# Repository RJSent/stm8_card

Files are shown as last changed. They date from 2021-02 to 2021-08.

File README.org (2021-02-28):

#+TITLE: stm8_card
#+AUTHOR: Richard Sent

* Overview

This is a work-in-progress project for an STM8 microcontroller powered
business card. I am using an STM8 alongside a OLED with a SSD1306
controller.

I've finished implementing most basic functionality (UART, I2C, etc)
and have begun working on the business card proper. There's still a
fair amount of work left to do. In particular, I need to implement
timers (instead of ~delay~), user input (debounced buttons), and a
low-power mode using interrupts. Of course, there's also more to be
done regarding the display itself!

I working to keep most of my code generic enough that I can reuse it
in future projects without needing to rework everything. It will act
as a miniature library of sorts for me to use. When that happens I
might move that to a different git project, and leave business card
specific code here.

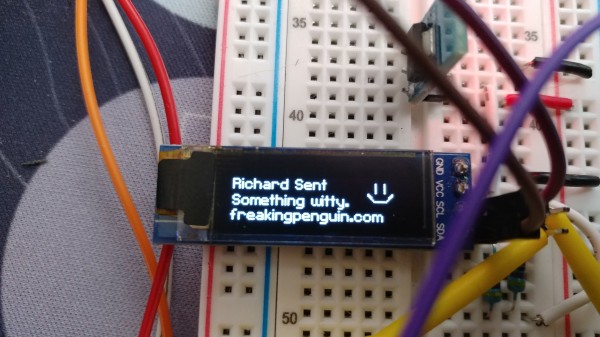
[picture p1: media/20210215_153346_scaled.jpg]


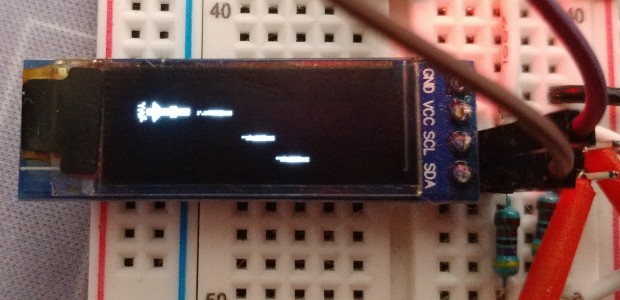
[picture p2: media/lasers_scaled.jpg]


[[file:media/working_lasers.mp4][Here's a demonstration of a work in progress space invaders game!]] We
can see that the player ship and lasers are functional and fully
animated. If you want to see the work that led up to this so far,
check out the media folder!

* License

This project is available under the terms of the [[https://opensource.org/licenses/MIT][MIT License]].

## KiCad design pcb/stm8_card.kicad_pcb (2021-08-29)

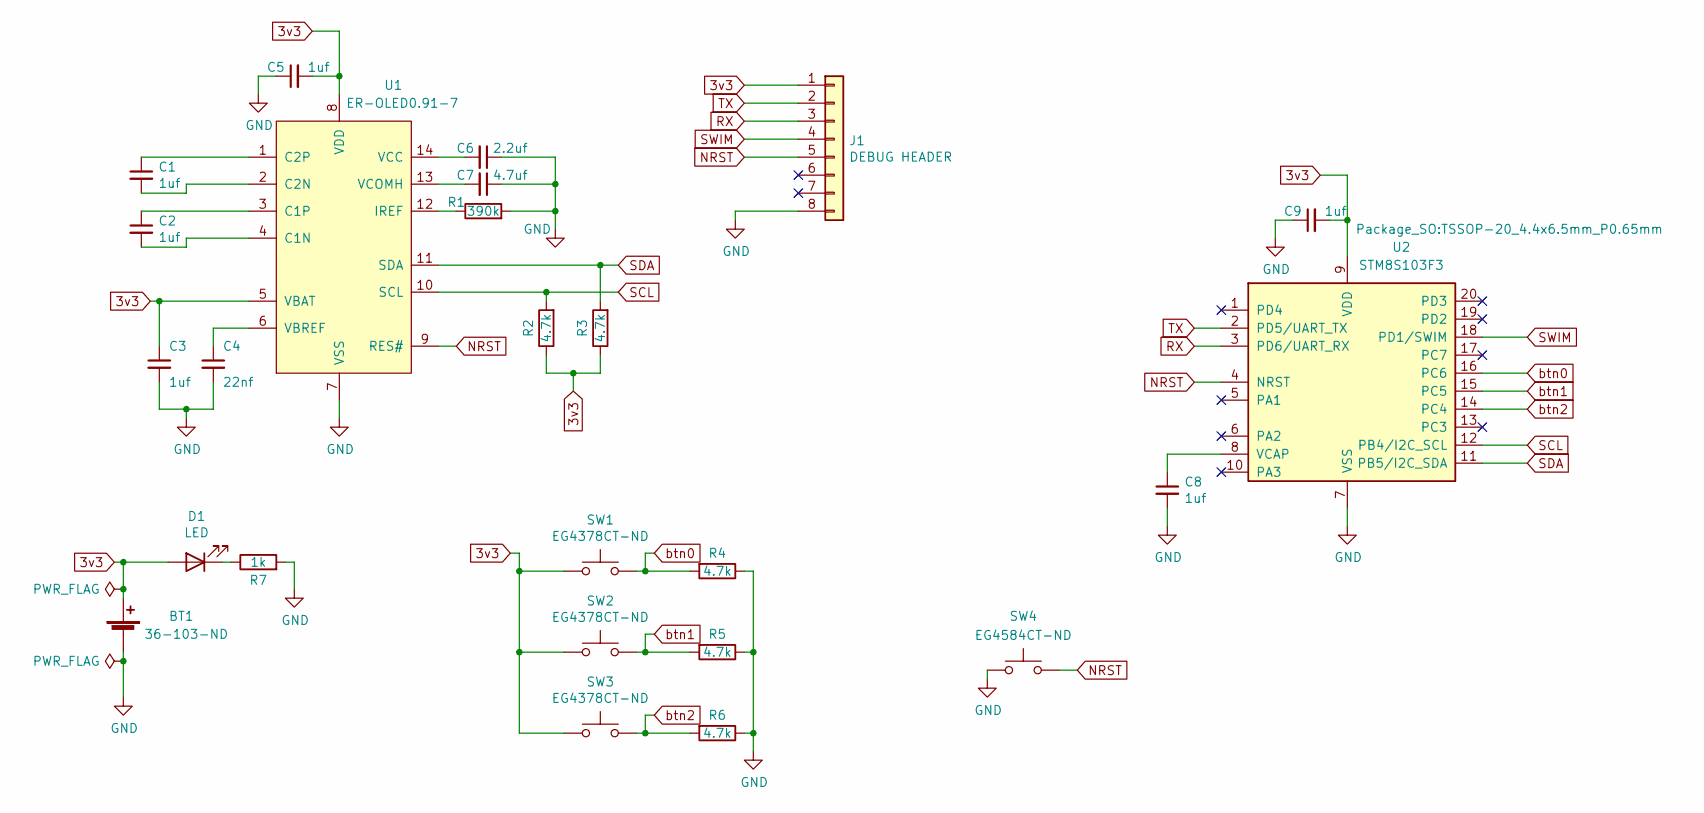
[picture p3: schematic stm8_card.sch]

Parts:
BT1: 103; BatteryHolder_Keystone_103_1x20mm_Corrected; digikey 36-103-ND
C1, C2, C3, C5, C8, C9: 1uf; C_0805_2012Metric_Pad1.18x1.45mm_HandSolder
C4: 22nf; C_0805_2012Metric_Pad1.18x1.45mm_HandSolder
C6: 2.2uf; C_0805_2012Metric_Pad1.18x1.45mm_HandSolder
C7: 4.7uf; C_0805_2012Metric_Pad1.18x1.45mm_HandSolder
D1: LED; LED_0805_2012Metric_Pad1.15x1.40mm_HandSolder; digikey 404-1316-1-ND
J1: DEBUG HEADER; 2mm_2x4_ICSP
R1: 390k; R_0805_2012Metric_Pad1.20x1.40mm_HandSolder
R2, R3, R4, R5, R6: 4.7k; R_0805_2012Metric_Pad1.20x1.40mm_HandSolder
R7: 1k; R_0805_2012Metric_Pad1.20x1.40mm_HandSolder
SW1, SW2, SW3: TL59AF100Q; digikey EG4378CT-ND
SW4: TL3302AF260QG; digikey EG4584CT-ND
U1: ER-OLED0.91-7
U2: STM8S103F3; TSSOP-20_4.4x6.5mm_P0.65mm

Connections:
3v3: BT1.1 (+), C3.1, C5.2, C9.2, D1.2 (A), J1.1, R2.1, R3.1, SW1.1, SW2.1, SW3.1, U1.5 (VBAT), U1.8 (VDD), U2.9 (VDD)
GND: BT1.2 (-), C3.2, C4.2, C5.1, C6.1, C7.1, C8.2, C9.1, J1.8, R1.2, R4.1, R5.1, R6.1, R7.2, SW4.1, U1.7 (VSS), U2.7 (VSS)
NRST: J1.5, SW4.2, U1.9 (RES#), U2.4 (NRST)
unnamed: C1.1, U1.1 (C2P)
unnamed: C1.2, U1.2 (C2N)
unnamed: C2.1, U1.3 (C1P)
unnamed: C2.2, U1.4 (C1N)
unnamed: C4.1, U1.6 (VBREF)
unnamed: C6.2, U1.14 (VCC)
unnamed: C7.2, U1.13 (VCOMH)
unnamed: C8.1, U2.8 (VCAP)
unnamed: D1.1 (K), R7.1
unnamed: R1.1, U1.12 (IREF)
RX: J1.3, U2.3 (PD6/UART_RX)
SCL: R2.2, U1.10 (SCL), U2.12 (PB4/I2C_SCL)
SDA: R3.2, U1.11 (SDA), U2.11 (PB5/I2C_SDA)
SWIM: J1.4, U2.18 (PD1/SWIM)
TX: J1.2, U2.2 (PD5/UART_TX)
btn0: R4.2, SW1.2, U2.16 (PC6)
btn1: R5.2, SW2.2, U2.15 (PC5)
btn2: R6.2, SW3.2, U2.14 (PC4)

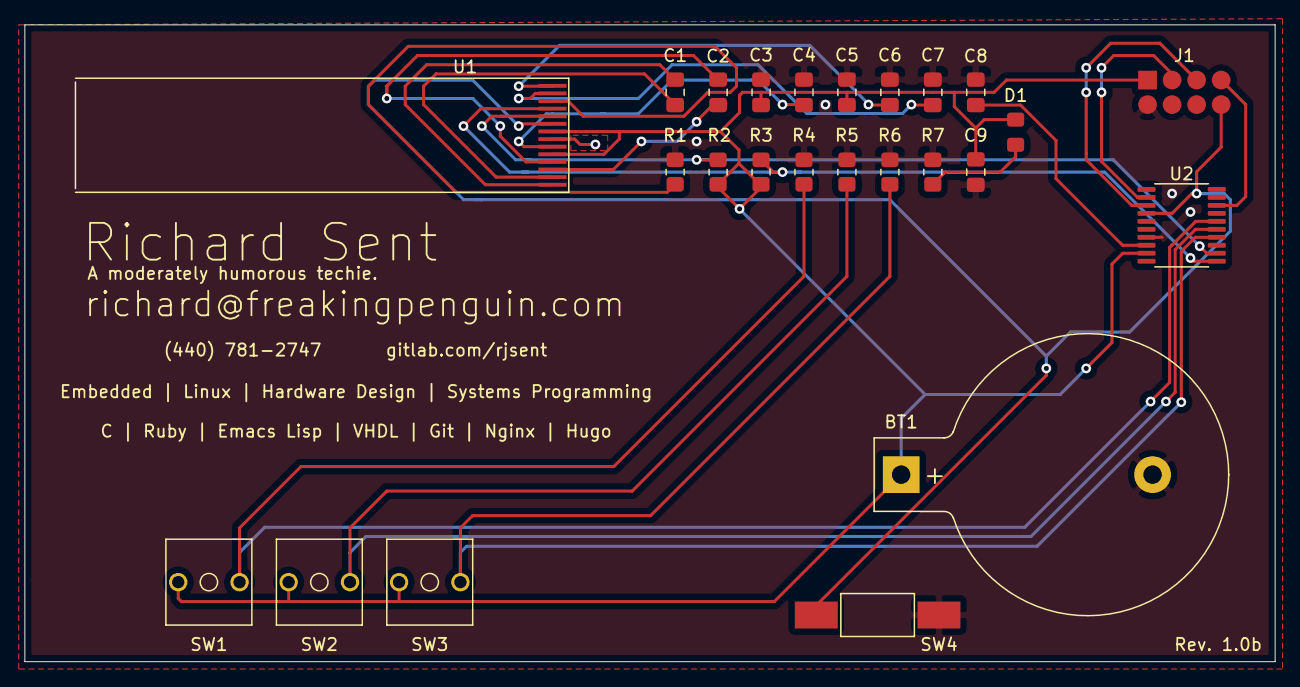
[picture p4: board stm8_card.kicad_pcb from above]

Board: 2 copper layers, 101.9 x 51.9 mm, 25 parts (0 on the bottom side), 21 nets.

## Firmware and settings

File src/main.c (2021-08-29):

#include <stdlib.h>

#include "baseline.h"
#include "i2c.h"
#include "uart.h"
#include "ssd1306.h"
#include "image.h"
#include "space_invader.h"
#include "gpio.h"

gpio_pin_t btn0 = { .port = 'C', .num = 6 };
gpio_pin_t btn1 = { .port = 'C', .num = 5 };
gpio_pin_t btn2 = { .port = 'C', .num = 4 };
gpio_pin_t led0 = { .port = 'A', .num = 1 };
gpio_pin_t led1 = { .port = 'A', .num = 2 };

static void initialize_gpio() {
  gpio_mode(&btn0, GPIO_INPUT_FLOAT);
  gpio_mode(&btn1, GPIO_INPUT_FLOAT);
  gpio_mode(&btn2, GPIO_INPUT_FLOAT);
  gpio_mode(&led0, GPIO_OUTPUT_PUSH_PULL);
  gpio_mode(&led1, GPIO_OUTPUT_PUSH_PULL);
}

/* TODO: move to power saving.c/h and take struct for what to gate */
static void periph_gating() {
  *CLK_PCKENR1 &= 0x1;           /* only i2c enabled */
  // *CLK_PCKENR1 |= 1 << 3;        /* enable uart1 */
  *CLK_PCKENR2 &= !(0x8C);      /* 0 to everything not reserved, rm0016 pg 96 */
}

static void power_saving() {
  clk_hsi_prescaler(1);
  clk_cpu_prescaler(128);        /* 125 kHz cpu */
  periph_gating();
  
}

static void initialize() {
  const int baud_rate = 9600;
  const long fmaster = 16000000;

  power_saving();

  uart_init(baud_rate, fmaster);
  i2c_init(2);
  initialize_gpio();
  ssd1306_init(SSD1306_I2C);
  invader_game_init(SSD1306_WIDTH, SSD1306_HEIGHT);
}

int main() {
  initialize();
  uart_printf("%s\n\r", __DATE__);
  char cycle_num = 0;
  const char max_cycles = 10;

  while (1) {
    /* uart_printf("-----CYCLE %d-----\n\r", cycle_num); */
      struct InvaderCommands invader_commands;
      if (gpio_read(&btn0)) {
	gpio_write(&led0, true);
	gpio_write(&led1, false);
	invader_commands.movement = DOWN;
      } else if (gpio_read(&btn1)) {
	gpio_write(&led0, false);
	gpio_write(&led1, true);
	invader_commands.movement = UP;
      } else {
	gpio_write(&led0, false);
	gpio_write(&led1, false);
	invader_commands.movement = NOP;
      }
      /* debounded input here. Maybe just have as timer though for
	 extra button to exit */
      if (random_upto(32) > 30) {
	invader_commands.shoot = TRUE;
      }
      struct DrawableImage *spaceship = debug_drawableimage_spaceship();
      invader_game_tick(&invader_commands);
      draw_image(spaceship, LEFT);
      struct DrawableImage *lasers[3];
      struct DrawableImage *invader_lasers[3];
      struct DrawableImage *invaders[3];
      for (int i = 0; i < 3; i++) {
	lasers[i] = debug_drawableimage_playerlaser(i);
	invader_lasers[i] = debug_drawableimage_invaderlaser(i);
	invaders[i] = debug_drawableimage_invader(i);
	draw_image(lasers[i], LEFT);
	draw_image(invader_lasers[i], LEFT);
	draw_image(invaders[i], LEFT);
      }
      draw_half(LEFT);
      clear_buffer();
      for (int i = 0; i < 3; i++) {
	draw_image(lasers[i], RIGHT);
	draw_image(invader_lasers[i], RIGHT);
	draw_image(invaders[i], RIGHT);
      }
      draw_half(RIGHT);
      clear_buffer();
      invader_commands.shoot = FALSE;
      /* delay(2000); */

    cycle_num++;

    /* if (cycle_num == max_cycles) { */
    /*   uart_printf("-----END-----\n\r"); */
    /* while(1) {}; */
    /* } */
    
    clear_buffer();    
  }
}

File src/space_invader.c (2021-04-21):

#include <stddef.h>
#include <stdint.h>

#include "space_invader.h"
#include "baseline.h"
/* #include "uart.h" */

/* TODO: Refactor code so that .state is a part of the PlayerLaser and PlayerShip structs */

/* TODO: Find safe way to calculate this */
#define NUM_SHIP_FRAMES              (3)
#define NUM_PLAYER_LASER_FRAMES      (4)
#define NUM_INVADER_FRAMES           (2)
#define NUM_INVADER_LASER_FRAMES     (2)
#define NUM_INVADER_EXPLOSION_FRAMES (4)

#define PLAYER_SHIP_TICKS_PER_FRAME   (2)
#define INVADER_TICKS_PER_FRAME       (26)
#define INVADER_LASER_TICKS_PER_FRAME (6)
#define INVADER_TICKS_BETWEEN_SPAWN   (32)

#define MAX_INVADERS        (3)
#define MAX_PLAYER_LASERS   (3)
#define MAX_INVADER_LASERS  (3)

#define PLAYER_LASER_VELOCITY   (game_width / 32)
#define INVADER_LASER_VELOCITY  (game_width / 32)

#define PLAYER_MAX_VELOCITY            (game_height / 8)
#define PLAYER_VELOCITY_TICKS_PER_GAIN (3) /* TODO: adjust in terms of game_height */
#define PLAYER_VELOCITY_GAIN_PER_TICK  (1)
#define PLAYER_VELOCITY_LOSS_PER_TICK  (1)
#define INVADER_Y_SPEED                (game_height / 16)
#define INVADER_X_SPEED                (game_width / 32)

#define INVADER_SPAWN_CHANCE (8) /* percentage out of 100 per tick */
#define INVADER_SHOOT_CHANCE (3)

typedef enum {STATUS_ALIVE, STATUS_EXPLODING, STATUS_DEAD} ship_status_t;

struct PlayerLaser {
  boolean_t active;
  struct DrawableImage laser;
};

struct PlayerShip {
  ship_status_t status;
  signed char velocity;
  unsigned char ticks_until_gain;
  struct DrawableImage ship;
  struct DrawableImage explosion;
};

/* TODO: Support different types of invaders. Maybe by different DrawableImage structs + a invader_num variable? Memory intensive... */
struct InvaderMob {
  ship_status_t status;
  enum InvaderDirection {INVADERDIRECTION_UP, INVADERDIRECTION_DOWN} direction;
  struct DrawableImage invader;
  struct DrawableImage explosion;
};

struct InvaderLaser {
  boolean_t active;
  struct DrawableImage laser;
};

const uint8_t spaceship_frame_0[24] = {
  0x01, 0x00, 0x00,
  0x01, 0x80, 0x00,
  0x41, 0xC1, 0xC0,
  0x6F, 0xFF, 0xFF,
  0x0F, 0xFF, 0xFF,
  0x81, 0xC1, 0xC0,
  0x11, 0x80, 0x00,
  0x41, 0x00, 0x00
};
const uint8_t spaceship_frame_1[24] = {
  0x01, 0x00, 0x00,
  0xC1, 0x80, 0x00,
  0x01, 0xC1, 0xC0,
  0x8F, 0xFF, 0xFF,
  0x2F, 0xFF, 0xFF,
  0x21, 0xC1, 0xC0,
  0x11, 0x80, 0x00,
  0x11, 0x00, 0x00
};
const uint8_t spaceship_frame_2[24] = {
  0x21, 0x00, 0x00,
  0x41, 0x80, 0x00,
  0x21, 0xC1, 0xC0,
  0x8F, 0xFF, 0xFF,
  0x0F, 0xFF, 0xFF,
  0x81, 0xC1, 0xC0,
  0x41, 0x80, 0x00,
  0x61, 0x00, 0x00
};

const uint8_t player_laser_frame_0[2] = { 0x3F, 0xDF };
const uint8_t player_laser_frame_1[2] = { 0xDF, 0xBF };
const uint8_t player_laser_frame_2[2] = { 0x7F, 0x1F };
const uint8_t player_laser_frame_3[2] = { 0x9F, 0x3F };

const uint8_t invader_1_frame_0[11] = {
  0x60, 0x18, 0x7C, 0xB6,       /* top half */
  0xAC, 0x2C, 0xAC,             /* middle part */
  0xB6, 0x7C, 0x18, 0x60        /* bottom part */
};
const uint8_t invader_1_frame_1[11] = {
  0x20, 0x19, 0x7C, 0xB6,       /* top half */
  0x2C, 0x2C, 0x2C,             /* middle part */
  0xB6, 0x7C, 0x19, 0x20        /* bottom part */
};

const uint8_t invader_explosion_frame_0[11] = {
  0x00, 0x00, 0x00, 0x18,
  0x24, 0x24, 0x24,
  0x18, 0x00, 0x00, 0x00
};
const uint8_t invader_explosion_frame_1[11] = {
  0x00, 0x00, 0x18,
  0x24, 0x42, 0x42, 0x42, 0x24,
  0x18, 0x00, 0x00
};
const uint8_t invader_explosion_frame_2[11] = {
  0x10, 0x24, 0x42,
  0x81, 0x01, 0x81, 0x80, 0x81,
  0x02, 0x24, 0x08
};
const uint8_t invader_explosion_frame_3[11] = {
  0x08, 0x24, 0x00,
  0x01, 0x80, 0x81, 0x01, 0x80,
  0x02, 0x00, 0x08
};


const uint8_t invader_laser_frame_0[3] = { 0x2A, 0xFF, 0x2A};
const uint8_t invader_laser_frame_1[3] = { 0x66, 0xFF, 0x66};


const struct Image spaceship_image_0 = {.width = 24, .height = 8, .pixels = spaceship_frame_0};
const struct Image spaceship_image_1 = {.width = 24, .height = 8, .pixels = spaceship_frame_1};
const struct Image spaceship_image_2 = {.width = 24, .height = 8, .pixels = spaceship_frame_2};

const struct Image player_laser_image_0 = {.width = 8, .height = 2, .pixels = player_laser_frame_0};
const struct Image player_laser_image_1 = {.width = 8, .height = 2, .pixels = player_laser_frame_1};
const struct Image player_laser_image_2 = {.width = 8, .height = 2, .pixels = player_laser_frame_2};
const struct Image player_laser_image_3 = {.width = 8, .height = 2, .pixels = player_laser_frame_3};

const struct Image invader_1_image_0 = {.width = 8, .height = 11, .pixels = invader_1_frame_0};
const struct Image invader_1_image_1 = {.width = 8, .height = 11, .pixels = invader_1_frame_1};

const struct Image invader_explosion_image_0 = {.width = 8, .height = 11, .pixels = invader_explosion_frame_0};
const struct Image invader_explosion_image_1 = {.width = 8, .height = 11, .pixels = invader_explosion_frame_1};
const struct Image invader_explosion_image_2 = {.width = 8, .height = 11, .pixels = invader_explosion_frame_2};
const struct Image invader_explosion_image_3 = {.width = 8, .height = 11, .pixels = invader_explosion_frame_3};

const struct Image invader_laser_image_0 = {.width = 8, .height = 3, .pixels = invader_laser_frame_0};
const struct Image invader_laser_image_1 = {.width = 8, .height = 3, .pixels = invader_laser_frame_1};


static struct PlayerShip  player_ship;
static struct PlayerLaser player_lasers[MAX_PLAYER_LASERS];
static struct InvaderMob  invader_mobs[MAX_INVADERS];
static struct InvaderLaser invader_lasers[MAX_INVADER_LASERS];

static unsigned char game_width, game_height;

#ifdef UART_H
void _debug_ship_tick(invader_movecmd_t movement) {
  static char tick_num = 0;
  uart_printf("---\n\r");
  uart_printf("tick: %d\n\r", tick_num++);
  if (movement == UP) {
    uart_printf("UP\n\r");
  } else if (movement == DOWN) {
    uart_printf("DOWN\n\r");
  } else if (movement == NOP) {
    uart_printf("NOP\n\r");
  } else {
    uart_printf("Invalid movement cmd\n\r");
  }
  uart_printf("vel: %d\n\r", player_ship.velocity);
  uart_printf("tug: %d\n\r", player_ship.ticks_until_gain);
  uart_printf("pos: %d\n\r", player_ship.ship.y);
}

void _debug_invader_tick() {
  for (unsigned char i = 0; i < MAX_INVADERS; i++) {
    if (invader_mobs[i].status == STATUS_ALIVE) {
      uart_printf("---\n\r");
      uart_printf("invader: %d\n\r", i);
      uart_printf("ypos: %d\t", invader_mobs[i].invader.y);
      uart_printf("xpos: %d\n\r", invader_mobs[i].invader.x);
    }
  }
  uart_printf("-----END TICK-----\n\r");
}
#endif
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

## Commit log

2021-02-01 UART transmission is functional with 9600 baud rate
2021-02-02 Some tiny changes to uart_printf
2021-02-05 functioning uart_printf with numbers
2021-02-05 clk prescaler functions, currently in baseline
2021-02-05 tidied up + split uart in header and source
2021-02-05 Cleaned up main + more uart format options
2021-02-05 Prep work for i2c and ssd1306
2021-02-13 Partially sorta kinda functional I2C code
    Managed to get it working with sending a
    I2C address and getting an ACK. I made some
    small changes that I can't recall and suddenly
    it isn't succeeding at that.
2021-02-13 fixed i2c issue
    Needed a small delay between start_cond and send_byte. Need a better
    solution with a guard in send_byte of some kind.
2021-02-14 i2c created guard for start bit
2021-02-14 Fully functioning 1-way I2C communication!
    Currently delay between sending addr is hardcoded. Definitely needs
    changing since the frequency might not be consistent.
2021-02-14 fixed issue when i2c_send_bytes() called too quickly
    the start condtion now isn't sent until the bus is free
2021-02-14 i2c NACK_ERROR guard + consistent transmission w/o hardcoded delay
2021-02-14 Further debugging i2c issue
2021-02-15 possibly fixed display size issue
    [main.c]
2021-02-15 CMD_HW_COM_PINS_CONFIG + 0x12 is almost certaintly the wrong setting.
    What should be 4 pixels tall is just 2.
    [main.c]
2021-02-15 Successfully printed an image to the display!!!
    I used https://javl.github.io/image2cpp/ to generate the byte array,
    using the "vertical - 1 bit per pixel" setting.
2021-02-20 printed compilation date on boot
2021-02-20 found issue with uart_printf
2021-02-20 experimenting with adding a framebuffer and drawing in two steps
2021-02-21 added const keyword to i2c_send_bytes due to warning. Maybe remove?
2021-02-21 demonstration code + video showing framebuffer use
2021-02-21 attached videos
2021-02-21 changed size from char to int in i2c_send_bytes and send_data
2021-02-22 removed unneeded printf + old todo
2021-02-22 mirror_buffer + invert + draw_pixel demo
    [main.c]
2021-02-22 x axis mirror demo
2021-02-22 figured out hsi_prescaler issue + changed some ints to chars
    [main.c]
2021-02-22 added flip_pixel method, current value of pixel is inverted
2021-02-26 made WIDTH and HEIGHT macros public + spaceship invert demo
    [main.c]
2021-02-27 removed uart dependency from i2c
2021-02-27 space_invader outlining. Worried about memory issues
    [space_invader.c]
2021-02-28 adjusted code to remove standard features SDCC doesn't support :(
    [space_invader.c]
2021-02-28 work on shoot laser and player laser tick methods
2021-02-28 partially functional shoot_laser and laser_tick code
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2021-02-28 added comment about interesting issue
    [space_invader.c]
2021-02-28 readme update + lasers picture
2021-02-28 removed uart + some more commenting
2021-02-28 slowed gain of velocity to try and give ship more weight
2021-02-28 changed scaled lasers image
2021-03-01 reworked ticks between velocity gains + debugging code
    [main.c, space_invader.c]
2021-03-03 fixed bug with my invader... typed i insted of ii
    also what the heck is up with sdcc suddenly complaining about resuing
    symbols now as opposed to before?
    [main.c, space_invader.c]
2021-03-03 adjustable delay between new frames
2021-03-03 working towards invaders shooting lasers
2021-03-03 more untested work on invader lasers
2021-03-03 begun testing code to debug issues with invaderlaser
    [main.c, space_invader.c]
2021-03-03 decrease maximum number of animation frames
2021-03-03 fixed bug with invader_lasers not working properly.
    Just missed stuff copying logic. Probably a sign i need to create
    smaller methods designed for working with the laser arrays
    [space_invader.c]
2021-03-03 video showing invader lasers
2021-03-11 fixed invader collision code! Still need to do something about score
    [main.c, space_invader.c]
2021-03-11 adjusted percents + fixed explosion animation!
    [main.c, space_invader.c]
2021-04-06 tried creating new makefile and project structure
    New errors pop up that never have before. Additionally the size of the
    final executable is larger than before. In fact, it's too large to
    flash to the microcontroller.
    [main.c, space_invader.c]
2021-04-18 adjusted main to test gpio, compilation fails
    Not 100% sure of compilation file, but I know it's not an sdcc version
    change. I checked out before branch, no issues. Could either be code
    or ?maybe? makefile. haven't checked
    [main.c]
2021-04-19 trying to fix pd1 cr1 issue
    see comment in main
    [main.c]
2021-04-20 "fixed" the gpio io issue + removed some code from registers
    TURNS OUT THERE WASN'T AN ISSUE AT ALL.
    PD1 is shared with SWIM, which is an active low communication
    protocol. I had the programmer connected to the SWIM pin, which has a
    separate header. When the SWIM cable is connected, the programmer
    brings that pin high, causing the LED I was using to try and verify if
    the pull-up was working to turn on. GPIO code is fully functional.
    Doesn't quite explain the peripheral dump being inaccurate, but
    honestly I'll take that at this point.
    [main.c]
2021-04-20 identified indirect cause of corruption issue
    Actually I don't even know at this point. Messing around with printfs
    ALSO fixed the issue, EVEN WHEN THE PRINTF IS RIGHT AFTER UART_INIT().
    YOU KNOW, THE 4TH LINE OF CODE TO BE EXECUTED!!
    [main.c]
2021-04-20 alternative fix to that doesn't require padding
    i dont even know honestly
    [main.c]
2021-04-20 identified possible root cause of error?
    [main.c]
2021-04-20 added comment about fix to main
    [main.c]
2021-04-20 space invader replaced 0 returns with NULL
    [space_invader.c]
2021-04-20 adjusted main loop to be less redundant
    "sub-cycle" based testing no longer needed
    [main.c]
2021-04-20 moved pins around
    now that the issue with PD1 is solved, no need to actually use that
    pin anymore
    [main.c]
2021-04-21 invader adjusted velocity parameters to have more "weight"
2021-04-21 pcb init
    [stm8_card.kicad_pcb, stm8_card.sch]
2021-04-22 pcb incomplete draft schematic
2021-04-22 pcb finished first schematic revision
    [stm8_card.sch]
2021-04-22 pcb one less backup file
2021-04-22 pcb one less tracked backup
2021-04-22 pcb added missing ground
    [stm8_card.sch]
2021-04-22 pcb capitalized stm8s103f3
    [stm8_card.sch]
2021-04-22 pcb improved schematic
    [stm8_card.sch]
2021-04-22 pcb created and assigned oled footprint
    [stm8_card.sch]
2021-04-22 pcb added 0805 handsolder footprints to C and R
    [stm8_card.sch]
2021-04-22 pcb debug icsp footprint
    [stm8_card.sch]
2021-04-22 pcb footprint for eg4378ct-nd
    [stm8_card.sch]
2021-04-22 pcb reset button footprint
    [stm8_card.sch]
2021-04-22 pcb actually applied sw footprints
    [stm8_card.sch]
2021-04-22 pcb board wip
    [stm8_card.kicad_pcb]
2021-04-22 pcb small edits
    [stm8_card.kicad_pcb]
2021-04-22 pcb corrected battery holder schematic to have closed perimeter
2021-04-22 updated dimensions
    [stm8_card.kicad_pcb]
2021-04-22 pcb updated bat footprint in schematic not just board
    [stm8_card.sch]
2021-04-22 pcb technically finished I think?
    [stm8_card.kicad_pcb]
2021-04-22 pcb more work on card
    [stm8_card.kicad_pcb]
2021-04-22 pcb readded ground planes
    [stm8_card.kicad_pcb]
2021-04-22 pcb removed some redundant vias
    [stm8_card.kicad_pcb]
2021-04-22 pcb hid ground via under mcu
    [stm8_card.kicad_pcb]
2021-04-22 pcb moved some vias a tiny bit
    [stm8_card.kicad_pcb]
2021-04-22 moved a singular via
    [stm8_card.kicad_pcb]
2021-04-23 pcb almost done! need to add mcu decoupling cap + correct v on back
    [stm8_card.kicad_pcb]
2021-04-23 small edits, still need to correct cap issue also add led + res
    [stm8_card.kicad_pcb]
2021-04-23 pcb improved pcb + added led, res, and mcu cap
    [stm8_card.kicad_pcb, stm8_card.sch]
2021-04-23 pcb improvements
    [stm8_card.kicad_pcb]
2021-04-23 pcb AESTHETIC
    [stm8_card.kicad_pcb]
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2021-04-24 pcb adjusted back btn traces
    [stm8_card.kicad_pcb]
2021-04-24 pcb adjusted front btn routes + other small edits
    [stm8_card.kicad_pcb]
2021-04-24 pcb edits
    [stm8_card.kicad_pcb]
2021-04-24 pcb removed 2 vias
    [stm8_card.kicad_pcb]
2021-04-24 pcb idk what i did
    [stm8_card.kicad_pcb]
2021-04-24 pcb centered some traces between c and rs
    [stm8_card.kicad_pcb]
2021-04-24 pcb aligned ssd1306 vias
    [stm8_card.kicad_pcb]
2021-04-24 pcb adjusted trace spacing
    [stm8_card.kicad_pcb]
2021-04-24 pcb ssd1306 routing
    [stm8_card.kicad_pcb]
2021-04-24 pcb small alignment + redundant traces
    [stm8_card.kicad_pcb]
2021-04-24 pcb ssd1306 gnd
    [stm8_card.kicad_pcb]
2021-04-25 pcb slightly moved silk text
    [stm8_card.kicad_pcb]
2021-04-25 pcb apparently some changes idk
    [stm8_card.kicad_pcb]
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2021-05-22 rescued schematic library to newer version I think???
    [stm8_card.sch]
2021-05-23 lowered brightness, about 0.15mA
2021-05-23 lowered charge pump, ~ 0.1mA
2021-05-23 saved another 0.6mA with periph gating
2021-08-29 rev 1.0b
    [stm8_card.kicad_pcb, stm8_card.sch]
